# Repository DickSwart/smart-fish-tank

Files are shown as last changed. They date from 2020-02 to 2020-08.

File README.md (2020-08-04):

# smart-fish-tank

<p align="center">
    SwartNinja logo
</p>

## Parts Used
---
- 1 x N-Channel MOSFET (IRF530N)
- 1 x NodeMCU V3.0
- 2 x Bi-Directional Logic Level Converter (JY-MCU)
- 1 x 12v to 5v Step Down
- 1 x 12V 6amp Power Supply
- 1 x Digital RGB Leds
- 1 x Project Box
- 1 x Power Jacks
- 1 x Toggle Switch
- Header Wires

## Fritzing Sketch
---
<p align="center">
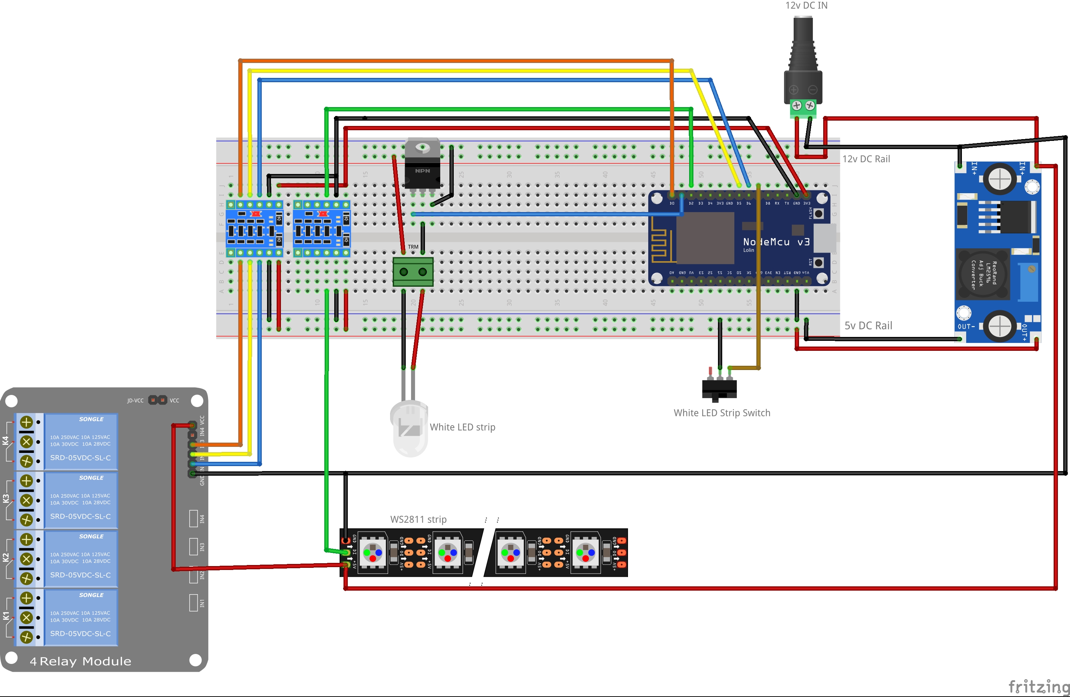
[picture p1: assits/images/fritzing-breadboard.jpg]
  
</p>

## Wiring
---

### Logic Shifter 1 - 5v Side
| Wire |  Pin | Destination | Destination Pin |
|---|---|---|---|
| Green | VCC | Step down converter 5v | positive |
| Purple | GND | Step down converter 5v | negative |
| Blue | 1<sup>*</sup> | Relay Module | IN1 |
| Green | 2<sup>*</sup> | Relay Module | IN2 |
| Brown | 3<sup>*</sup> | Relay Module | IN3 |
| Purple | 4<sup>*</sup> | Relay Module | IN4 |

### Logic Shifter 1 - 3.3v Side
| Wire |  Pin | Destination | Destination Pin |
|---|---|---|---|
| Orange | VCC | NodeMCU | 3v |
| Black | GND | NodeMCU | G |
| Blue | 1<sup>*</sup> | NodeMCU | D6 |
| Purple | 2<sup>*</sup> | NodeMCU | D5 |
| Gray | 3<sup>*</sup> | NodeMCU | D0 |
| Green | 4<sup>*</sup> | - | - |

### Logic Shifter 2 - 5v Side
| Wire |  Pin | Destination | Destination Pin |
|---|---|---|---|
| Green | VCC | Step down converter 5v | positive |
| Purple | GND | Step down converter 5v | negative |
| Brown | 1<sup>*</sup> | Terminal Block | 4 |
| - | 2<sup>*</sup> | - | - |
| - | 3<sup>*</sup> | - | - |
| - | 4<sup>*</sup> | - | - |

### Logic Shifter 2 - 3.3v Side
| Wire |  Pin | Destination | Destination Pin |
|---|---|---|---|
| Orange | VCC | NodeMCU | 3v |
| White | GND | NodeMCU | G |
| Orange | 1<sup>*</sup> | NodeMCU | D2 |
| - | 2<sup>*</sup> | - | - |
| - | 3<sup>*</sup> | - | - |
| - | 4<sup>*</sup> | - | - |

_* numbering starts from next to the GND incrementing from left to right pin as there is no physical numbering on the board_

### Terminal Block
| Pin | Function |
|--|--|
| 1 | White & Color LED VCC (Step down converter 12v positive) |
| 2 | White LED GND |
| 3 | Color LED GND (Step down converter 12v negative) |
| 4 | Color LED Signal |
| 5 | Switch Signal (connected to D7 on NodeMCU) |
| 6 | Switch Ground (connected to G on NodeMCU) |

### Fish Tank Light Wire
| Color | Function |
|--|--|
| brown | White & Color LED VCC  |
| Black | White LED - GND |
| Green | Color LED - Signal |
| White | Color LED - GND |
| Orange | Switch |
| Blue | Switch |

## Photo
---
More photos and other assets available in the assits folder.
<p align="center">
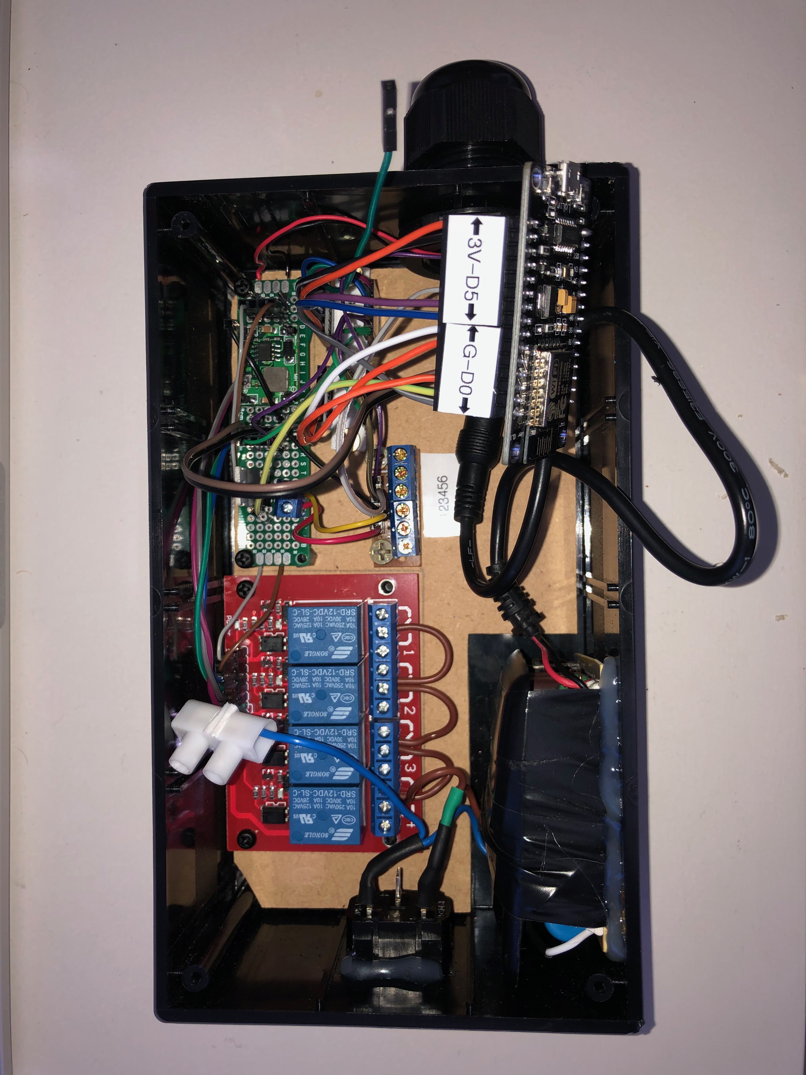
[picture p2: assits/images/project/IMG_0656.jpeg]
  
</p>

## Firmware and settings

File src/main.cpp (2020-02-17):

#define FASTLED_ESP8266_RAW_PIN_ORDER
#define FASTLED_INTERRUPT_RETRY_COUNT 0

#include <Arduino.h>
#include <ESP8266WiFi.h>  //if you get an error here you need to install the ESP8266 board manager
#include <ESP8266mDNS.h>  //if you get an error here you need to install the ESP8266 board manager
#include <PubSubClient.h> //https://github.com/knolleary/pubsubclient
#include <ArduinoOTA.h>   //https://github.com/esp8266/Arduino/tree/master/libraries/ArduinoOTA
#include <SimpleTimer.h>  //https://github.com/marcelloromani/Arduino-SimpleTimer/tree/master/SimpleTimer
#include "FastLED.h"

#include <SwartNinjaRSW.h>
#include <SwartNinjaSW.h>
#include <SwartNinjaLED.h>

#include "user_config.h" // Fixed user configurable options
#ifdef USE_CONFIG_OVERRIDE
#include "user_config_override.h" // Configuration overrides for my_user_config.h
#endif

///////////////////////////////////////////////////////////////////////////
//   General Declarations
///////////////////////////////////////////////////////////////////////////

char ESP_CHIP_ID[7] = {0};
char OTA_HOSTNAME[sizeof(ESP_CHIP_ID) + sizeof(OTA_HOSTNAME_TEMPLATE) - 2] = {0};

///////////////////////////////////////////////////////////////////////////
//   WiFi
///////////////////////////////////////////////////////////////////////////
// function declaration
void setupWiFi(void);
void connectWiFi(void);
void onConnected(const WiFiEventStationModeConnected &event);
void onDisconnect(const WiFiEventStationModeDisconnected &event);
void onGotIP(const WiFiEventStationModeGotIP &event);
void loopWiFiSensor(void);
int getWiFiSignalStrength(void);

// variables declaration
int previousWiFiSignalStrength = -1;
unsigned long previousMillis = 0;
int reqConnect = 0;
int isConnected = 0;
const long interval = 500;
const long reqConnectNum = 15; // number of intervals to wait for connection
WiFiEventHandler mConnectHandler;
WiFiEventHandler mDisConnectHandler;
WiFiEventHandler mGotIpHandler;

// Initialize the Ethernet mqttClient object
WiFiClient wifiClient;

/* -------------------------------------------------
 *  MQTT
 * ------------------------------------------------- */
// function declaration
void setupMQTT();
void connectToMQTT();
void checkInMQTT();
void subscribeToMQTT(char *p_topic);
void publishToMQTT(char *p_topic, char *p_payload, bool retain = true);
void handleMQTTMessage(char *topic, byte *payload, unsigned int length);

// variables declaration
bool boot = true;
char MQTT_CHAR_PAYLOAD[50];
char MQTT_PAYLOAD[8] = {0};
char MQTT_AVAILABILITY_TOPIC[sizeof(ESP_CHIP_ID) + sizeof(MQTT_AVAILABILITY_TOPIC_TEMPLATE) - 2] = {0};
char MQTT_WIFI_QUALITY_TOPIC[sizeof(ESP_CHIP_ID) + sizeof(MQTT_SENSOR_TOPIC_TEMPLATE) + sizeof(WIFI_QUALITY_SENSOR_NAME) - 4] = {0};

// main light
char MQTT_MAIN_LIGHT_STATE_TOPIC[sizeof(ESP_CHIP_ID) + sizeof(MQTT_MAIN_LIGHT_STATE_TOPIC_TEMPLATE) - 2] = {0};
char MQTT_MAIN_LIGHT_CMND_TOPIC[sizeof(ESP_CHIP_ID) + sizeof(MQTT_MAIN_LIGHT_CMND_TOPIC_TEMPLATE) - 2] = {0};
char MQTT_MAIN_LIGHT_BRIGHTNESS_STATE_TOPIC[sizeof(ESP_CHIP_ID) + sizeof(MQTT_MAIN_LIGHT_BRIGHTNESS_STATE_TEMPLATE) - 2] = {0};
char MQTT_MAIN_LIGHT_BRIGHTNESS_CMND_TOPIC[sizeof(ESP_CHIP_ID) + sizeof(MQTT_MAIN_LIGHT_BRIGHTNESS_CMND_TEMPLATE) - 2] = {0};
// main light
char MQTT_COLOR_LIGHT_POWER_STATE_TOPIC[sizeof(ESP_CHIP_ID) + sizeof(MQTT_COLOR_LIGHT_POWER_STATE_TEMPLATE) - 2] = {0};
char MQTT_COLOR_LIGHT_POWER_CMND_TOPIC[sizeof(ESP_CHIP_ID) + sizeof(MQTT_COLOR_LIGHT_POWER_CMND_TEMPLATE) - 2] = {0};
char MQTT_COLOR_LIGHT_BRIGHTNESS_STATE_TOPIC[sizeof(ESP_CHIP_ID) + sizeof(MQTT_COLOR_LIGHT_BRIGHTNESS_STATE_TEMPLATE) - 2] = {0};
char MQTT_COLOR_LIGHT_BRIGHTNESS_CMND_TOPIC[sizeof(ESP_CHIP_ID) + sizeof(MQTT_COLOR_LIGHT_BRIGHTNESS_CMND_TEMPLATE) - 2] = {0};
char MQTT_COLOR_LIGHT_COLOR_STATE_TOPIC[sizeof(ESP_CHIP_ID) + sizeof(MQTT_COLOR_LIGHT_COLOR_STATE_TEMPLATE) - 2] = {0};
char MQTT_COLOR_LIGHT_COLOR_CMND_TOPIC[sizeof(ESP_CHIP_ID) + sizeof(MQTT_COLOR_LIGHT_COLOR_CMND_TEMPLATE) - 2] = {0};

// relay module [size of chip id + size of relay name + size of template - size of template place hold characters ("%s")]
char MQTT_RELAY01_STATE_TOPIC[sizeof(ESP_CHIP_ID) + sizeof(RELAY01_NAME) + sizeof(MQTT_RELAY_STATE_TEMPLATE) - 4] = {0};
char MQTT_RELAY01_COMMAND_TOPIC[sizeof(ESP_CHIP_ID) + sizeof(RELAY01_NAME) + sizeof(MQTT_RELAY_COMMAND_TEMPLATE) - 4] = {0};
char MQTT_RELAY02_STATE_TOPIC[sizeof(ESP_CHIP_ID) + sizeof(RELAY02_NAME) + sizeof(MQTT_RELAY_STATE_TEMPLATE) - 4] = {0};
char MQTT_RELAY02_COMMAND_TOPIC[sizeof(ESP_CHIP_ID) + sizeof(RELAY02_NAME) + sizeof(MQTT_RELAY_COMMAND_TEMPLATE) - 4] = {0};
char MQTT_RELAY03_STATE_TOPIC[sizeof(ESP_CHIP_ID) + sizeof(RELAY02_NAME) + sizeof(MQTT_RELAY_STATE_TEMPLATE) - 4] = {0};
char MQTT_RELAY03_COMMAND_TOPIC[sizeof(ESP_CHIP_ID) + sizeof(RELAY02_NAME) + sizeof(MQTT_RELAY_COMMAND_TEMPLATE) - 4] = {0};

// Initialize the mqtt mqttClient object
PubSubClient mqttClient(wifiClient);

///////////////////////////////////////////////////////////////////////////
// SwartNinjaLED
///////////////////////////////////////////////////////////////////////////
// function declaration
void publishLightBrightness(void);
void publishLightState(void);

// variables declaration
bool stripStateChanged = false;

// Initialize the LED object
SwartNinjaLED mainLight(MAIN_LIGHT_PIN);

///////////////////////////////////////////////////////////////////////////
//   FastLED
///////////////////////////////////////////////////////////////////////////
// function declaration
void chooseColorLightPattern();

bool colorLightsPower = false;
byte brightness = 255;
String effect = "None";
byte current_red = 0;
byte current_green = 0;
byte current_blue = 0;

// Initialize the mqtt FastLED object
CRGB colorLight[COLOR_LIGHT_NUM_LEDS];

///////////////////////////////////////////////////////////////////////////
//  SwartNinjaRSW
///////////////////////////////////////////////////////////////////////////
// function declaration
void handleSwartNinjaSensorUpdate(char *value, int pin, const char *event);
// initialize the SwartNinjaRSW object
SwartNinjaRSW lightSwitch(LIGHT_SWITCH_PIN, handleSwartNinjaSensorUpdate, false);

///////////////////////////////////////////////////////////////////////////
//  SwartNinjaSW
///////////////////////////////////////////////////////////////////////////
// Initialise the relay module
SwartNinjaSW relay01(RELAY01_PIN);
SwartNinjaSW relay02(RELAY02_PIN);
SwartNinjaSW relay03(RELAY03_PIN);

// add relays to an array
SwartNinjaSW relayModule[3] = {relay01, relay02, relay03};

///////////////////////////////////////////////////////////////////////////
//   SimpleTimer
///////////////////////////////////////////////////////////////////////////
SimpleTimer timer;

///////////////////////////////////////////////////////////////////////////
//  MAIN SETUP AND LOOP
///////////////////////////////////////////////////////////////////////////

void setup()
{
  Serial.begin(115200);

  boot = true;

  // set the chip ID
  sprintf(ESP_CHIP_ID, "%06X", ESP.getChipId());

  // WIFI
  setupWiFi();

  // MQTT
  setupMQTT();

  // Over the air
  sprintf(OTA_HOSTNAME, OTA_HOSTNAME_TEMPLATE, ESP_CHIP_ID);
  Serial.print("AOT Hostname: ");
  Serial.println(OTA_HOSTNAME);
  ArduinoOTA.setHostname(OTA_HOSTNAME);
  ArduinoOTA.begin();

  delay(10);

  // light switch setup
  lightSwitch.setup();

  mainLight.setup();

  // setup color light
  FastLED.addLeds<COLOR_LIGHT_LED_TYPE, COLOR_LIGHT_PIN, COLOR_LIGHT_COLOR_ORDER>(colorLight, COLOR_LIGHT_NUM_LEDS);
  FastLED.setDither(0);

  // relay module
  for (unsigned int i = 0; i < sizeof(relayModule) / sizeof(relayModule[0]); i++)
  {
    relayModule[i].setup();
  }

  timer.setInterval(120000, checkInMQTT);
}

void loop()
{
  // WIFI
  connectWiFi();

  // Code will only run if connected to WiFi
  if (isConnected == 2)
  {
    // MQTT
    if (!mqttClient.connected())
    {
      connectToMQTT();
    }
    mqttClient.loop();

    // Over the air
    if (!colorLightsPower)
    {
      ArduinoOTA.handle();
    }

    // Check WiFi signal
    loopWiFiSensor();

    // color light
    chooseColorLightPattern();
    FastLED.show(brightness);

    timer.run();
  }

  // light switch loop
  lightSwitch.loop();
}

///////////////////////////////////////////////////////////////////////////
//  SwartNinjaRSW
///////////////////////////////////////////////////////////////////////////
void handleSwartNinjaSensorUpdate(char *value, int pin, const char *event)
{
  if (event == SN_RSW_SENSOR_EVT)
  {
    bool mainLightState = !mainLight.getRawState();
    if (mainLight.setState(mainLightState))
    {
      publishToMQTT(MQTT_MAIN_LIGHT_STATE_TOPIC, mainLight.getState());
    }
  }
}

///////////////////////////////////////////////////////////////////////////
//   FastLED
///////////////////////////////////////////////////////////////////////////
void chooseColorLightPattern()
{
  if (colorLightsPower)
  {
    if (effect == "SomeEffect")
    {
      // need to create effects.
    }
    else
    {
      fill_solid(colorLight, COLOR_LIGHT_NUM_LEDS, CRGB(current_red, current_green, current_blue));
    }
  }
  else
  {
    fill_solid(colorLight, COLOR_LIGHT_NUM_LEDS, CRGB::Black);
  }
}

///////////////////////////////////////////////////////////////////////////
//   WiFi
///////////////////////////////////////////////////////////////////////////

/*
 * Function called to setup WiFi module
 */
void setupWiFi(void)
{
  WiFi.disconnect();
  WiFi.persistent(false);
  WiFi.mode(WIFI_STA);

  mConnectHandler = WiFi.onStationModeConnected(onConnected);
  mDisConnectHandler = WiFi.onStationModeDisconnected(onDisconnect);
  mGotIpHandler = WiFi.onStationModeGotIP(onGotIP);
}

/*
 * Function called to connect to WiFi
 */
void connectWiFi(void)
{
  if (WiFi.status() != WL_CONNECTED && reqConnect > reqConnectNum && isConnected < 2)
  {
    reqConnect = 0;
    isConnected = 0;
    WiFi.disconnect();

    Serial.println();
    Serial.print("[WIFI]: Attempting to connect to WPA SSID: ");
    Serial.println(WIFI_SSID);

    WiFi.hostname(WIFI_HOSTNAME);
    WiFi.begin(WIFI_SSID, WIFI_PASSWORD);
    Serial.println("[WIFI]: Connecting...");
  }

  unsigned long currentMillis = millis();
  if (currentMillis - previousMillis >= interval)
  {
    previousMillis = currentMillis;
    reqConnect++;
  }
}

/*
 * Function called to handle WiFi events
 */
void onConnected(const WiFiEventStationModeConnected &event)
{
  char macAdddress[20];
  sprintf(macAdddress, "%02X:%02X:%02X:%02X:%02X:%02X", event.bssid[5], event.bssid[4], event.bssid[3], event.bssid[2], event.bssid[1], event.bssid[0]);
  Serial.print(F("[WIFI]: You're connected to the AP. (MAC - "));
  Serial.print(macAdddress);
  Serial.println(")");
  isConnected = 1;
}

void onDisconnect(const WiFiEventStationModeDisconnected &event)
{
  Serial.println("[WIFI]: Disconnected");
  Serial.print("[WIFI]: Reason: ");
  Serial.println(event.reason);
  isConnected = 0;
}

void onGotIP(const WiFiEventStationModeGotIP &event)
{
  Serial.print("[WIFI]: IP Address : ");
  Serial.println(event.ip);
  Serial.print("[WIFI]: Subnet     : ");
  Serial.println(event.mask);
  Serial.print("[WIFI]: Gateway    : ");
  Serial.println(event.gw);

  isConnected = 2;
}

/*
 * Function to check WiFi signal strength
 */
void loopWiFiSensor(void)
{
  static unsigned long lastWiFiQualityMeasure = 0;
  if (lastWiFiQualityMeasure + WIFI_QUALITY_INTERVAL <= millis() || previousWiFiSignalStrength == -1)
  {
    lastWiFiQualityMeasure = millis();
    int currentWiFiSignalStrength = getWiFiSignalStrength();
    if (isnan(previousWiFiSignalStrength) || currentWiFiSignalStrength <= previousWiFiSignalStrength - WIFI_QUALITY_OFFSET_VALUE || currentWiFiSignalStrength >= previousWiFiSignalStrength + WIFI_QUALITY_OFFSET_VALUE)
    {
      previousWiFiSignalStrength = currentWiFiSignalStrength;
      dtostrf(currentWiFiSignalStrength, 2, 2, MQTT_PAYLOAD);
      publishToMQTT(MQTT_WIFI_QUALITY_TOPIC, MQTT_PAYLOAD);
    }
  }
}

/*
 * Helper function to get the current WiFi signal strength
 */
int getWiFiSignalStrength(void)
{
  if (WiFi.status() != WL_CONNECTED)
    return -1;
  int dBm = WiFi.RSSI();
  if (dBm <= -100)
    return 0;
  if (dBm >= -50)
    return 100;
  return 2 * (dBm + 100);
}

///////////////////////////////////////////////////////////////////////////
//   MQTT
///////////////////////////////////////////////////////////////////////////

/*
 * Function called to setup MQTT topics
 */
void setupMQTT()
{
  sprintf(MQTT_AVAILABILITY_TOPIC, MQTT_AVAILABILITY_TOPIC_TEMPLATE, ESP_CHIP_ID);
  Serial.println();
  Serial.println("---------------------------------------------------------------------------");
  Serial.print(F("[MQTT]: MQTT availability topic: "));
  Serial.println(MQTT_AVAILABILITY_TOPIC);

  sprintf(MQTT_WIFI_QUALITY_TOPIC, MQTT_SENSOR_TOPIC_TEMPLATE, ESP_CHIP_ID, WIFI_QUALITY_SENSOR_NAME);
  Serial.print(F("[MQTT]: MQTT WiFi Quality topic: "));
  Serial.println(MQTT_WIFI_QUALITY_TOPIC);
  Serial.println("---------------------------------------------------------------------------");

  sprintf(MQTT_MAIN_LIGHT_STATE_TOPIC, MQTT_MAIN_LIGHT_STATE_TOPIC_TEMPLATE, ESP_CHIP_ID);
  Serial.print(F("[MQTT]: MQTT Main Light State topic: "));
  Serial.println(MQTT_MAIN_LIGHT_STATE_TOPIC);

  sprintf(MQTT_MAIN_LIGHT_CMND_TOPIC, MQTT_MAIN_LIGHT_CMND_TOPIC_TEMPLATE, ESP_CHIP_ID);
  Serial.print(F("[MQTT]: MQTT Main Light Command topic: "));
  Serial.println(MQTT_MAIN_LIGHT_CMND_TOPIC);

  sprintf(MQTT_MAIN_LIGHT_BRIGHTNESS_STATE_TOPIC, MQTT_MAIN_LIGHT_BRIGHTNESS_STATE_TEMPLATE, ESP_CHIP_ID);
  Serial.print(F("[MQTT]: MQTT Main Light Brightness State topic: "));
  Serial.println(MQTT_MAIN_LIGHT_BRIGHTNESS_STATE_TOPIC);

  sprintf(MQTT_MAIN_LIGHT_BRIGHTNESS_CMND_TOPIC, MQTT_MAIN_LIGHT_BRIGHTNESS_CMND_TEMPLATE, ESP_CHIP_ID);
  Serial.print(F("[MQTT]: MQTT Main Light Brightness Command topic: "));
  Serial.println(MQTT_MAIN_LIGHT_BRIGHTNESS_CMND_TOPIC);
  Serial.println("---------------------------------------------------------------------------");

  sprintf(MQTT_COLOR_LIGHT_POWER_STATE_TOPIC, MQTT_COLOR_LIGHT_POWER_STATE_TEMPLATE, ESP_CHIP_ID);
  Serial.print(F("[MQTT]: MQTT Color Light power State topic: "));
  Serial.println(MQTT_COLOR_LIGHT_POWER_STATE_TOPIC);

  sprintf(MQTT_COLOR_LIGHT_POWER_CMND_TOPIC, MQTT_COLOR_LIGHT_POWER_CMND_TEMPLATE, ESP_CHIP_ID);
  Serial.print(F("[MQTT]: MQTT Color Light power Command topic: "));
  Serial.println(MQTT_COLOR_LIGHT_POWER_CMND_TOPIC);

  sprintf(MQTT_COLOR_LIGHT_BRIGHTNESS_STATE_TOPIC, MQTT_COLOR_LIGHT_BRIGHTNESS_STATE_TEMPLATE, ESP_CHIP_ID);
  Serial.print(F("[MQTT]: MQTT Color Light Brightness State topic: "));
  Serial.println(MQTT_COLOR_LIGHT_BRIGHTNESS_STATE_TOPIC);

  sprintf(MQTT_COLOR_LIGHT_BRIGHTNESS_CMND_TOPIC, MQTT_COLOR_LIGHT_BRIGHTNESS_CMND_TEMPLATE, ESP_CHIP_ID);
  Serial.print(F("[MQTT]: MQTT Color Light Brightness Command topic: "));
  Serial.println(MQTT_COLOR_LIGHT_BRIGHTNESS_CMND_TOPIC);

  sprintf(MQTT_COLOR_LIGHT_COLOR_STATE_TOPIC, MQTT_COLOR_LIGHT_COLOR_STATE_TEMPLATE, ESP_CHIP_ID);
  Serial.print(F("[MQTT]: MQTT Color Light color State topic: "));
  Serial.println(MQTT_COLOR_LIGHT_COLOR_STATE_TOPIC);

  sprintf(MQTT_COLOR_LIGHT_COLOR_CMND_TOPIC, MQTT_COLOR_LIGHT_COLOR_CMND_TEMPLATE, ESP_CHIP_ID);
  Serial.print(F("[MQTT]: MQTT Color Light color Command topic: "));
  Serial.println(MQTT_COLOR_LIGHT_COLOR_CMND_TOPIC);
  Serial.println("---------------------------------------------------------------------------");

  sprintf(MQTT_RELAY01_STATE_TOPIC, MQTT_RELAY_STATE_TEMPLATE, ESP_CHIP_ID, RELAY01_NAME);
  Serial.print(F("[MQTT]: MQTT relay01 State topic: "));
  Serial.println(MQTT_RELAY01_STATE_TOPIC);

  sprintf(MQTT_RELAY01_COMMAND_TOPIC, MQTT_RELAY_COMMAND_TEMPLATE, ESP_CHIP_ID, RELAY01_NAME);
  Serial.print(F("[MQTT]: MQTT relay01 Command topic: "));
  Serial.println(MQTT_RELAY01_COMMAND_TOPIC);

  sprintf(MQTT_RELAY02_STATE_TOPIC, MQTT_RELAY_STATE_TEMPLATE, ESP_CHIP_ID, RELAY02_NAME);
  Serial.print(F("[MQTT]: MQTT relay02 State topic: "));
  Serial.println(MQTT_RELAY02_STATE_TOPIC);

  sprintf(MQTT_RELAY02_COMMAND_TOPIC, MQTT_RELAY_COMMAND_TEMPLATE, ESP_CHIP_ID, RELAY02_NAME);
  Serial.print(F("[MQTT]: MQTT relay02 Command topic: "));
  Serial.println(MQTT_RELAY02_COMMAND_TOPIC);

  sprintf(MQTT_RELAY03_STATE_TOPIC, MQTT_RELAY_STATE_TEMPLATE, ESP_CHIP_ID, RELAY03_NAME);
  Serial.print(F("[MQTT]: MQTT relay03 State topic: "));
  Serial.println(MQTT_RELAY03_STATE_TOPIC);

  sprintf(MQTT_RELAY03_COMMAND_TOPIC, MQTT_RELAY_COMMAND_TEMPLATE, ESP_CHIP_ID, RELAY03_NAME);
  Serial.print(F("[MQTT]: MQTT relay03 Command topic: "));
  Serial.println(MQTT_RELAY03_COMMAND_TOPIC);

  Serial.println("---------------------------------------------------------------------------");

  mqttClient.setServer(MQTT_SERVER, MQTT_SERVER_PORT);
  mqttClient.setCallback(handleMQTTMessage);
}

void handleMQTTMessage(char *topic, byte *payload, unsigned int length)
{
  String newTopic = topic;
  payload[length] = '\0';
  String newPayload = String((char *)payload);

  Serial.print("[MQTT]: handleMQTTMessage - Message arrived, topic: ");
  Serial.print(topic);
  Serial.print(", payload: ");
  Serial.println(newPayload);
  Serial.println();
  newPayload.toCharArray(MQTT_CHAR_PAYLOAD, newPayload.length() + 1);

  if (newTopic == MQTT_MAIN_LIGHT_CMND_TOPIC)
  {
    if (mainLight.setState(newPayload.equalsIgnoreCase(MQTT_PAYLOAD_ON)))
    {
      publishToMQTT(MQTT_MAIN_LIGHT_STATE_TOPIC, mainLight.getState());
    }
  }
  else if (String(MQTT_MAIN_LIGHT_BRIGHTNESS_CMND_TOPIC).equals(newTopic))
  {
    // test if the payload is equal to "ON" or "OFF"
    if (mainLight.setBrightness(newPayload.toInt()))
    {
      publishToMQTT(MQTT_MAIN_LIGHT_BRIGHTNESS_STATE_TOPIC, mainLight.getBrightness());
    }
  }
  else if (String(MQTT_COLOR_LIGHT_POWER_CMND_TOPIC).equals(newTopic))
  {
    colorLightsPower = String(newPayload).equals(MQTT_PAYLOAD_ON);
    publishToMQTT(MQTT_COLOR_LIGHT_POWER_STATE_TOPIC, MQTT_CHAR_PAYLOAD);
  }
  else if (String(MQTT_COLOR_LIGHT_BRIGHTNESS_CMND_TOPIC).equals(newTopic))
  {
    brightness = newPayload.toInt();
    publishToMQTT(MQTT_COLOR_LIGHT_POWER_STATE_TOPIC, MQTT_CHAR_PAYLOAD);
  }
  else if (String(MQTT_COLOR_LIGHT_COLOR_CMND_TOPIC).equals(newTopic))
  {
    publishToMQTT(MQTT_COLOR_LIGHT_COLOR_STATE_TOPIC, MQTT_CHAR_PAYLOAD);

    // get the position of the first and second commas
    uint8_t firstIndex = newPayload.indexOf(',');
    uint8_t lastIndex = newPayload.lastIndexOf(',');

    uint8_t red = newPayload.substring(0, firstIndex).toInt();
    uint8_t green = newPayload.substring(firstIndex + 1, lastIndex).toInt();
    uint8_t blue = newPayload.substring(lastIndex + 1).toInt();
    if ((red < 0 || red > 255) || (green < 0 || green > 255) || (blue < 0 || blue > 255))
    {
      return;
    }
    // update current color values
    current_red = red;
    current_green = green;
    current_blue = blue;
  }
  else if (String(MQTT_RELAY01_COMMAND_TOPIC).equals(newTopic)) {
    if (relay01.setState(newPayload.equalsIgnoreCase(MQTT_PAYLOAD_ON)))
    {
      publishToMQTT(MQTT_RELAY01_STATE_TOPIC, relay01.getState());
    }
  }
  else if (String(MQTT_RELAY02_COMMAND_TOPIC).equals(newTopic)) {
    if (relay02.setState(newPayload.equalsIgnoreCase(MQTT_PAYLOAD_ON)))
    {
      publishToMQTT(MQTT_RELAY02_STATE_TOPIC, relay02.getState());
    }
  }
  else if (String(MQTT_RELAY03_COMMAND_TOPIC).equals(newTopic)) {
    if (relay03.setState(newPayload.equalsIgnoreCase(MQTT_PAYLOAD_ON)))
    {
      publishToMQTT(MQTT_RELAY03_STATE_TOPIC, relay03.getState());
    }
  }

}

/*
  Function called to connect/reconnect to the MQTT broker
*/
void connectToMQTT()
{
  int retries = 0;
  // Loop until we're connected / reconnected
  while (!mqttClient.connected())
  {
    if (retries < 150)
    {
      Serial.println("[MQTT]: Attempting MQTT connection...");
      if (mqttClient.connect(ESP_CHIP_ID, MQTT_USERNAME, MQTT_PASSWORD, MQTT_AVAILABILITY_TOPIC, 0, 1, "offline"))
      {

        Serial.println(F("[MQTT]: The mqttClient is successfully connected to the MQTT broker"));
        publishToMQTT(MQTT_AVAILABILITY_TOPIC, "online");
        if (boot)
        {
          Serial.println(F("[MQTT]: Rebooted"));
          boot = false;
        }
        else
        {
          Serial.println(F("[MQTT]: Reconnected"));
        }

        // publish messages
        // subscribeToMQTT(MQTT_COLOR_LIGHT_POWER_STATE_TOPIC);
        // subscribeToMQTT(MQTT_COLOR_LIGHT_COLOR_STATE_TOPIC);

        // ... and resubscribe
        subscribeToMQTT(MQTT_MAIN_LIGHT_CMND_TOPIC);
        subscribeToMQTT(MQTT_MAIN_LIGHT_BRIGHTNESS_CMND_TOPIC);
        subscribeToMQTT(MQTT_COLOR_LIGHT_POWER_CMND_TOPIC);
        subscribeToMQTT(MQTT_COLOR_LIGHT_COLOR_CMND_TOPIC);
        subscribeToMQTT(MQTT_COLOR_LIGHT_BRIGHTNESS_CMND_TOPIC);
        subscribeToMQTT(MQTT_RELAY01_COMMAND_TOPIC);
        subscribeToMQTT(MQTT_RELAY02_COMMAND_TOPIC);
        subscribeToMQTT(MQTT_RELAY03_COMMAND_TOPIC);
      }
      else
      {
        retries++;
        Serial.println(F("[MQTT]: ERROR - The connection to the MQTT broker failed"));
        Serial.print(F("[MQTT]: MQTT username: "));
        Serial.println(MQTT_USERNAME);
        Serial.print(F("[MQTT]: MQTT password: "));
        Serial.println(MQTT_PASSWORD);
        Serial.print(F("[MQTT]: MQTT broker: "));
        Serial.println(MQTT_SERVER);
        Serial.print(F("[MQTT]: Retries: "));
        Serial.println(retries);
        // Wait 5 seconds before retrying
        delay(5000);
      }
    }
    if (retries > 149)
    {
      ESP.restart();
    }
  }
}

void checkInMQTT()
{
  publishToMQTT(MQTT_AVAILABILITY_TOPIC, "online", false);
  timer.setTimeout(120000, checkInMQTT);
}
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

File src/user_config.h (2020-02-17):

#ifndef _USER_CONFIG_H_
#define _USER_CONFIG_H_

///////////////////////////////////////////////////////////////////////////
//   WIFI
///////////////////////////////////////////////////////////////////////////
#define WIFI_SSID "wifi_ssid"
#define WIFI_PASSWORD "wifi_password"
#define WIFI_HOSTNAME "SmartFishTank"
#define WIFI_QUALITY_OFFSET_VALUE 2
#define WIFI_QUALITY_INTERVAL 50000 // [ms]
#define WIFI_QUALITY_SENSOR_NAME "wifi"

///////////////////////////////////////////////////////////////////////////
//   MQTT
///////////////////////////////////////////////////////////////////////////
#define MQTT_SERVER "xxx.xxx.xxx.xxx"
#define MQTT_SERVER_PORT 1883
#define MQTT_USERNAME "mqtt_user_name"
#define MQTT_PASSWORD "mqtt_password"

#define MQTT_AVAILABILITY_TOPIC_TEMPLATE "%s/status" // MQTT availability: online/offline
#define MQTT_SENSOR_TOPIC_TEMPLATE "%s/sensor/%s"
#define MQTT_STATE_TOPIC_TEMPLATE "%s/%s/state"
#define MQTT_COMMAND_TOPIC_TEMPLATE "cmnd/%s/%s"

#define MQTT_MAIN_LIGHT_STATE_TOPIC_TEMPLATE "%s/main-light/power"
#define MQTT_MAIN_LIGHT_CMND_TOPIC_TEMPLATE "cmnd/%s/main-light/power"
#define MQTT_MAIN_LIGHT_BRIGHTNESS_STATE_TEMPLATE "%s/main-light/brightness"
#define MQTT_MAIN_LIGHT_BRIGHTNESS_CMND_TEMPLATE "cmnd/%s/main-light/brightness"

#define MQTT_COLOR_LIGHT_POWER_STATE_TEMPLATE "%s/color-light/power"
#define MQTT_COLOR_LIGHT_POWER_CMND_TEMPLATE "cmnd/%s/color-light/power"
#define MQTT_COLOR_LIGHT_BRIGHTNESS_STATE_TEMPLATE "%s/color-light/brightness"
#define MQTT_COLOR_LIGHT_BRIGHTNESS_CMND_TEMPLATE "cmnd/%s/color-light/brightness"
#define MQTT_COLOR_LIGHT_COLOR_STATE_TEMPLATE "%s/color-light/color"
#define MQTT_COLOR_LIGHT_COLOR_CMND_TEMPLATE "cmnd/%s/color-light/color"

#define MQTT_RELAY_STATE_TEMPLATE "%s/%s/state"
#define MQTT_RELAY_COMMAND_TEMPLATE "cmnd/%s/%s/set"

#define MQTT_PAYLOAD_ON "ON"
#define MQTT_PAYLOAD_OFF "OFF"

///////////////////////////////////////////////////////////////////////////
//   FastLED
///////////////////////////////////////////////////////////////////////////
#define COLOR_LIGHT_NUM_LEDS 20
#define COLOR_LIGHT_LED_TYPE WS2811
#define COLOR_LIGHT_COLOR_ORDER BRG //Color orders, can be RGB, RBG, GRB, GBR, BRG, BGR
#define COLOR_LIGHT_PIN 4 // pin D2 on nodemcu

///////////////////////////////////////////////////////////////////////////
//   MAIN LIGHT
///////////////////////////////////////////////////////////////////////////
#define MAIN_LIGHT_PIN D1

///////////////////////////////////////////////////////////////////////////
//   LIGHT SWITCH
///////////////////////////////////////////////////////////////////////////
#define LIGHT_SWITCH_PIN D7

///////////////////////////////////////////////////////////////////////////
//   RELAY MODULE
///////////////////////////////////////////////////////////////////////////
#define RELAY01_NAME "relay01"
#define RELAY01_PIN D6

#define RELAY02_NAME "relay02"
#define RELAY02_PIN D5

#define RELAY03_NAME "relay03"
#define RELAY03_PIN D0

///////////////////////////////////////////////////////////////////////////
//   Over-the-Air update (OTA)
///////////////////////////////////////////////////////////////////////////
#define OTA_HOSTNAME_TEMPLATE WIFI_HOSTNAME "_%s"
#define OTA_PORT 8266 // port 8266 by default

#endif // _USER_CONFIG_H_

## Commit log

2020-02-17 added relays
2020-02-17 added fritzing
    [breadboard.fzz]
2020-02-18 Updated readme and added fritzing bb image
    [breadboard.fzz]
